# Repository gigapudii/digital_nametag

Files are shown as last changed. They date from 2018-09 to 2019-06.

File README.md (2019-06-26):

# Digital nametag
A digital nametag based on the Nokia 3310 screen, making you interesting during fairs.

## WHY
Whenever I visit fairs, I often feel that I am not noticed very much. And when I do find someone to speak to, I sometimes find it hard to start a conversation. 

digital-nametag-front

## HOW
The solution is a digital nametag. It can be used as a conversation starter and help show your creativity to the public. Aside of this, it gives you the possibility to present parts of your CV as well as contact information without having to spell it out loud everytime.

For the nametag you will need a screen to begin with. Nokia 3310 screens are big enough and apparently still sold online. Aside of this, you will need an Attiny85, a coin cell battery (CR2032), an on/off switch, and a button to power up the backlight of the screen. 

As for the microcontroller, the Attiny85 is preferred because it's a) low powered b) cheap and c) has just enough pins to drive the screen.

To design the board, Eagle CAD was used. The basic thought during the design process was to make it "invisible", i.e. have it hidden behind the screen, and for it to have a small cut on the top to be hanged through. Apart from this, the most important part was to make the correct connections between the board and the screen which was fairly straight forward. 

digital-nametag-back
digital-nametag-size

As for the software, the screen is controlled through an [Arduino library](https://github.com/platisd/nokia-5110-lcd-library). Additionally, when the screen is not updated, the microcontroller is in deep sleep to preserve the battery.

To create the images that were displayed on the screen, Adobe Photoshop and the LCD Assistant were mainly used.

## Components
* [Nametag PCB](https://oshpark.com/shared_projects/H9KOpiVm)
* Attiny85
* Coin cell battery CR2032
* Coin cell battery holder
* On/off switch
* Backlight button
* Resistor (for the backlight)

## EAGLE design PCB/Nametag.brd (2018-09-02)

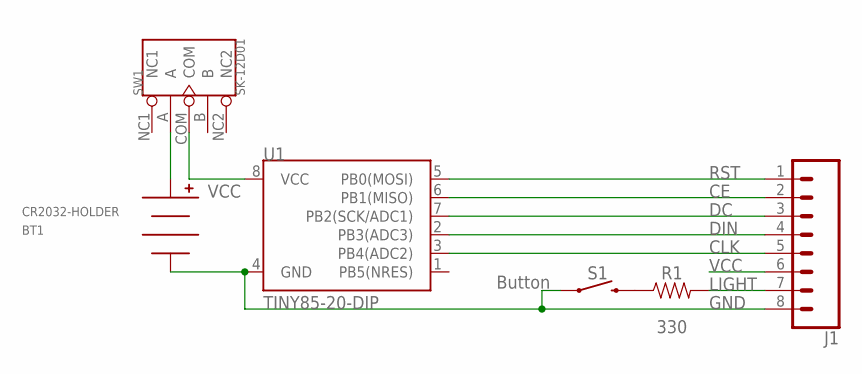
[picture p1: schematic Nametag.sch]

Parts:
BT1: CR2032-HOLDER; CH28-2032LF
J1: CONN_08"; 1X08
R1: 330; AXIAL-0.3
S1: Button; TACTILE_SWITCH_PTH_6.0MM
SW1: SK-12D01; SW5-2.0-8.8X4.4X4.7MM-90D
U1: TINY85-20-DIP; DIP08_MCU

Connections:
CE: J1.2, U1.6 (PB1(MISO))
CLK: J1.5, U1.3 (PB4(ADC2))
DC: J1.3, U1.7 (PB2(SCK/ADC1))
DIN: J1.4, U1.2 (PB3(ADC3))
GND: BT1.NEG, J1.8, S1.1, U1.4 (GND)
LIGHT: J1.7, R1.P$2 (2)
unnamed: R1.P$1 (1), S1.3 (2)
unnamed: BT1.POS, SW1.A
RST: J1.1, U1.5 (PB0(MOSI))
VCC: J1.6, SW1.COM, U1.8 (VCC)

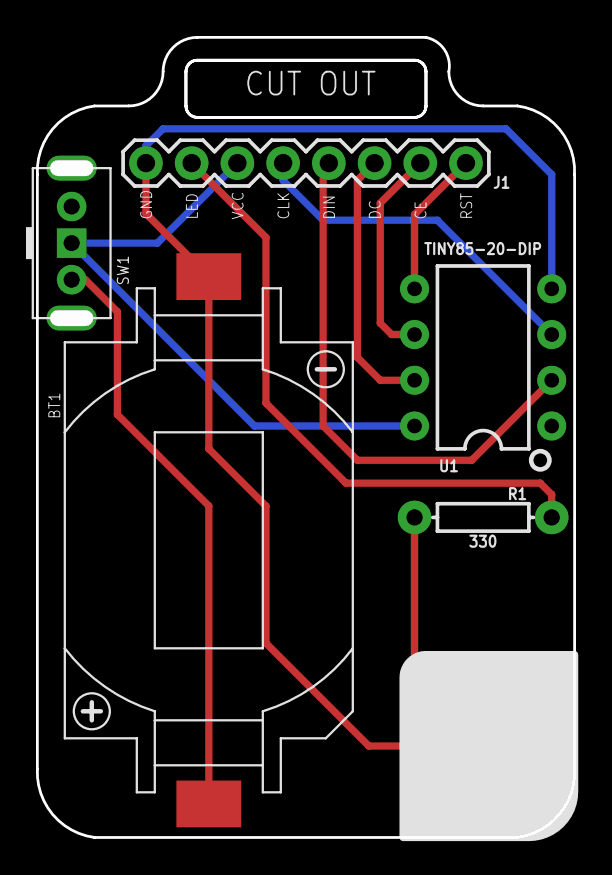
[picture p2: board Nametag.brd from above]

Board: 2 copper layers, 29.8 x 44.5 mm, 6 parts (0 on the bottom side), 10 nets.

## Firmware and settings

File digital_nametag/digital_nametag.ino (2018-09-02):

/**
 * Digital nametag
 * Author: Patricia Ilin aka Gigapudii
 * Bitmaps generated with LCD Assistant and Adobe Photoshop
 * Deep sleep code taken from https://github.com/platisd/dialectic-ball/
 * Nokia LCD library: https://github.com/platisd/nokia-5110-lcd-library
 */

#include <Nokia_LCD.h>
#include <avr/sleep.h>
#include <avr/power.h>
#include <avr/wdt.h>
#include <avr/interrupt.h>
#include <avr/pgmspace.h>

const unsigned char hellopic [] PROGMEM = {
0x00, 0xFC, 0xFC, 0x00, 0x00, 0xFC, 0xFC, 0x0C, 0x0C, 0xCC, 0xCC, 0xCC, 0xCC, 0xCC, 0xCC, 0xCC,
0xCC, 0xCC, 0xCC, 0xCC, 0xCC, 0xCC, 0xCC, 0xCC, 0xCC, 0xCC, 0xCC, 0xCC, 0xCC, 0xCC, 0xCC, 0xCC,
0xCC, 0xCC, 0xCC, 0xCC, 0xCC, 0xCC, 0xCC, 0xCC, 0xCC, 0xCC, 0xCC, 0xCC, 0xCC, 0xCC, 0xCC, 0xCC,
0xCC, 0xCC, 0xCC, 0xCC, 0xCC, 0xCC, 0xCC, 0xCC, 0xCC, 0xCC, 0xCC, 0xCC, 0xCC, 0xCC, 0xCC, 0xCC,
0xCC, 0xCC, 0xCC, 0xCC, 0xCC, 0xCC, 0xCC, 0xCC, 0xCC, 0xCC, 0xCC, 0xCC, 0xCC, 0xCC, 0x0C, 0x0C,
0xFC, 0xFC, 0x00, 0x00, 0x00, 0xFF, 0xFF, 0x00, 0x00, 0xFF, 0xFF, 0x00, 0x00, 0xFF, 0xFF, 0x00,
0x00, 0x00, 0xFC, 0xFC, 0x0C, 0x0C, 0x0C, 0x0C, 0x0C, 0x0C, 0x0C, 0x0C, 0x0C, 0x0C, 0x0C, 0x0C,
0x0C, 0x0C, 0x0C, 0x0C, 0x0C, 0x0C, 0x0C, 0x0C, 0x0C, 0x0C, 0x0C, 0x0C, 0x0C, 0x0C, 0x0C, 0x0C,
0x0C, 0x0C, 0x0C, 0x0C, 0x0C, 0x0C, 0x0C, 0x0C, 0x0C, 0x0C, 0x0C, 0x0C, 0x0C, 0x0C, 0x0C, 0x0C,
0x0C, 0x0C, 0x0C, 0x0C, 0x0C, 0x0C, 0x0C, 0x0C, 0x0C, 0x0C, 0x0C, 0x0C, 0xFC, 0xFC, 0x00, 0x00,
0xFF, 0xFF, 0x00, 0x00, 0xFF, 0xFF, 0x00, 0x00, 0x00, 0xFF, 0xFF, 0x00, 0x00, 0xFF, 0xFF, 0x00,
0x00, 0xFF, 0xFF, 0x00, 0x00, 0x00, 0xFF, 0xFF, 0x00, 0x00, 0x00, 0x00, 0x00, 0xFE, 0xFE, 0x20,
0x20, 0xFE, 0xFE, 0x00, 0x00, 0x00, 0x00, 0xFE, 0xFE, 0x22, 0x22, 0x22, 0x02, 0x00, 0x00, 0x00,
0x00, 0xFE, 0xFE, 0x00, 0x00, 0x00, 0x00, 0x00, 0x00, 0x00, 0x00, 0xFE, 0xFE, 0x00, 0x00, 0x00,
0x00, 0x00, 0x00, 0x00, 0x00, 0xFC, 0xFE, 0x02, 0x02, 0xFE, 0xFC, 0x00, 0x00, 0x00, 0x00, 0x00,
0xFF, 0xFF, 0x00, 0x00, 0xFF, 0xFF, 0x00, 0x00, 0xFF, 0xFF, 0x00, 0x00, 0x00, 0xFF, 0xFF, 0x00,
0x00, 0xFF, 0xFF, 0x00, 0x00, 0xFF, 0xFF, 0x00, 0x00, 0x00, 0xFF, 0xFF, 0x00, 0x00, 0x00, 0x00,
0x00, 0x03, 0x03, 0x00, 0x00, 0x03, 0x03, 0x00, 0x00, 0x00, 0x00, 0x03, 0x03, 0x02, 0x02, 0x02,
0x02, 0x00, 0x00, 0x00, 0x00, 0x03, 0x03, 0x02, 0x02, 0x02, 0x02, 0x00, 0x00, 0x00, 0x00, 0x03,
0x03, 0x02, 0x02, 0x02, 0x02, 0x00, 0x00, 0x00, 0x00, 0x01, 0x03, 0x02, 0x02, 0x03, 0x01, 0x00,
0x00, 0x00, 0x00, 0x00, 0xFF, 0xFF, 0x00, 0x00, 0xFF, 0xFF, 0x00, 0x00, 0xFF, 0xFF, 0x00, 0x00,
0x00, 0xFF, 0xFF, 0x00, 0x00, 0xFF, 0xFF, 0x00, 0x00, 0x3F, 0x3F, 0x30, 0x30, 0x30, 0x33, 0x33,
0x33, 0x33, 0x33, 0x33, 0x33, 0x33, 0x33, 0x33, 0x33, 0x33, 0x33, 0x33, 0x33, 0x33, 0x33, 0x33,
0x33, 0x33, 0x33, 0x33, 0x33, 0x33, 0x33, 0x33, 0x33, 0x33, 0x33, 0x33, 0x33, 0x33, 0x33, 0x33,
0x33, 0x33, 0x33, 0x33, 0x33, 0x33, 0x33, 0x33, 0x33, 0x33, 0x33, 0x33, 0x33, 0x33, 0x33, 0x33,
0x33, 0x33, 0x33, 0x33, 0x33, 0x33, 0x30, 0x30, 0x3F, 0x3F, 0x00, 0x00, 0xFF, 0xFF, 0x00, 0x00,
0xFF, 0xFF, 0x00, 0x00, 0x00, 0x3F, 0x3F, 0x30, 0x30, 0x33, 0x33, 0x33, 0x33, 0x33, 0x33, 0x33,
0x33, 0x33, 0x33, 0x33, 0x33, 0x33, 0x33, 0x33, 0x33, 0x33, 0x33, 0x33, 0x33, 0x33, 0x33, 0x33,
0x33, 0x33, 0x33, 0x33, 0x33, 0x33, 0x33, 0x33, 0x33, 0x33, 0x33, 0x33, 0x33, 0x33, 0x33, 0x33,
0x33, 0x33, 0x33, 0x33, 0x33, 0x33, 0x33, 0x33, 0x33, 0x33, 0x33, 0x33, 0x33, 0x33, 0x33, 0x33,
0x33, 0x33, 0x33, 0x33, 0x33, 0x33, 0x33, 0x33, 0x33, 0x33, 0x33, 0x33, 0x33, 0x33, 0x33, 0x33,
0x33, 0x33, 0x30, 0x30, 0x3F, 0x3F, 0x00, 0x00, 
};

const unsigned char nicetomeetyou [] PROGMEM = {
0x00, 0x00, 0xFC, 0x18, 0x60, 0x80, 0xFC, 0x00, 0x00, 0xF4, 0x00, 0x00, 0xE0, 0x10, 0x10, 0x10,
0x00, 0xE0, 0x50, 0x50, 0x60, 0x00, 0x00, 0x00, 0x00, 0x10, 0xF8, 0x10, 0x00, 0xE0, 0x10, 0x10,
0x10, 0xE0, 0x00, 0x00, 0x00, 0x00, 0xF0, 0x10, 0x10, 0xF0, 0x10, 0xF0, 0x00, 0x00, 0xE0, 0x50,
0x50, 0x60, 0x00, 0xE0, 0x50, 0x50, 0x60, 0x00, 0x10, 0xF8, 0x10, 0x00, 0x00, 0x00, 0x00, 0x70,
0x80, 0xC0, 0x30, 0x00, 0xE0, 0x10, 0x10, 0x10, 0xE0, 0x00, 0xF0, 0x00, 0x00, 0xF0, 0x00, 0x00,
0x00, 0x7C, 0x00, 0x00, 0x00, 0x00, 0x83, 0x00, 0x00, 0x01, 0x83, 0x00, 0x00, 0x03, 0x00, 0x00,
0x01, 0x02, 0x02, 0x02, 0x00, 0x01, 0x02, 0x82, 0x82, 0x80, 0x80, 0x00, 0x00, 0x00, 0x03, 0x02,
0x00, 0x01, 0x02, 0x02, 0x02, 0x01, 0x00, 0x00, 0x00, 0x00, 0x03, 0x80, 0x00, 0x03, 0x00, 0x03,
0x00, 0x00, 0x81, 0x02, 0x02, 0x02, 0x00, 0x01, 0x02, 0x02, 0x02, 0x00, 0x00, 0x03, 0x02, 0x00,
0x00, 0x00, 0x00, 0x10, 0x1F, 0x03, 0x00, 0x00, 0x01, 0x02, 0x02, 0x02, 0x01, 0x00, 0x03, 0x02,
0x02, 0x03, 0x00, 0x00, 0x00, 0x03, 0x00, 0x00, 0x00, 0x00, 0x7F, 0x00, 0x00, 0x00, 0x01, 0x00,
0x7E, 0x02, 0x02, 0x7E, 0x02, 0x7E, 0x00, 0x00, 0x00, 0x00, 0x00, 0x7F, 0x08, 0x08, 0x0C, 0x07,
0x00, 0x70, 0x52, 0x12, 0x7E, 0x00, 0x00, 0x02, 0x7F, 0x42, 0x00, 0x7E, 0x02, 0x02, 0x00, 0x7E,
0x00, 0x3C, 0x42, 0x42, 0x42, 0x00, 0x7E, 0x00, 0x00, 0x70, 0x52, 0x12, 0x7E, 0x00, 0x00, 0x60,
0x00, 0x00, 0x00, 0x00, 0x00, 0x00, 0x00, 0x00, 0x00, 0x00, 0x00, 0x00, 0x00, 0x00, 0x00, 0x00,
0x00, 0x00, 0x00, 0x00, 0x00, 0x00, 0x00, 0x00, 0x00, 0x00, 0x00, 0x00, 0x00, 0x00, 0x00, 0x00,
0x00, 0x00, 0x00, 0x00, 0x00, 0x00, 0x00, 0x00, 0x00, 0x00, 0x00, 0x00, 0x00, 0x00, 0x00, 0x00,
0x00, 0x00, 0x00, 0x00, 0x00, 0x00, 0x00, 0x00, 0x00, 0x00, 0x00, 0x00, 0x00, 0x00, 0x00, 0x00,
0x00, 0x00, 0x00, 0x00, 0x00, 0x00, 0x00, 0x00, 0x00, 0x00, 0x00, 0x00, 0x00, 0x00, 0x00, 0x00,
0x00, 0x00, 0x00, 0x00, 0x00, 0x00, 0x00, 0x00, 0x00, 0x00, 0x00, 0x00, 0x00, 0x00, 0x00, 0x00,
0x00, 0x00, 0x00, 0x00, 0x00, 0x00, 0x00, 0x00, 0x00, 0x00, 0x00, 0x00, 0x00, 0x00, 0x00, 0x00,
0x00, 0x00, 0xF8, 0x80, 0x80, 0xF8, 0x00, 0xE0, 0x30, 0x18, 0x18, 0x38, 0xE0, 0x00, 0x78, 0xE0,
0x80, 0x78, 0x80, 0xE0, 0x38, 0x00, 0x00, 0x00, 0x00, 0x00, 0xF0, 0x18, 0xE0, 0x00, 0x00, 0x00,
0xF8, 0x98, 0xF0, 0x00, 0x00, 0xE0, 0x30, 0x18, 0x18, 0x38, 0xE0, 0x00, 0x00, 0x00, 0xF8, 0x00,
0x00, 0xF8, 0x00, 0x00, 0x18, 0xF8, 0x18, 0x00, 0x00, 0x00, 0x00, 0x08, 0x78, 0x80, 0xF8, 0x08,
0x00, 0xE0, 0x30, 0x18, 0x18, 0x38, 0xE0, 0x00, 0x00, 0xF8, 0x00, 0x00, 0xF8, 0x00, 0x10, 0x18,
0xF0, 0x00, 0x00, 0x00, 0x00, 0x00, 0x3F, 0x01, 0x01, 0x3F, 0x00, 0x0F, 0x38, 0x30, 0x30, 0x18,
0x0F, 0x00, 0x00, 0x3F, 0x3F, 0x00, 0x3F, 0x3F, 0x00, 0x00, 0x00, 0x00, 0x00, 0x38, 0x0F, 0x06,
0x1F, 0x38, 0x00, 0x00, 0x3F, 0x31, 0x31, 0x1F, 0x00, 0x0F, 0x38, 0x30, 0x30, 0x18, 0x0F, 0x00,
0x00, 0x00, 0x1F, 0x30, 0x30, 0x1F, 0x00, 0x00, 0x00, 0x3F, 0x00, 0x00, 0x00, 0x00, 0x00, 0x00,
0x00, 0x3F, 0x00, 0x00, 0x00, 0x0F, 0x38, 0x30, 0x30, 0x18, 0x0F, 0x00, 0x00, 0x1F, 0x30, 0x30,
0x1F, 0x00, 0x00, 0x3B, 0x00, 0x00, 0x00, 0x00, 
};

const unsigned char datatjej_logo [] PROGMEM = {
  0x00, 0x00, 0x00, 0x00, 0x00, 0x00, 0x00, 0x00, 0x00, 0x00, 0x00, 0x00, 0x00, 0x00, 0x00, 0x00,
  0x00, 0x00, 0x00, 0x00, 0x00, 0x00, 0x00, 0x00, 0x00, 0x00, 0xFF, 0xFF, 0xFF, 0xFF, 0xFF, 0xFF,
  0xFF, 0xFF, 0xFF, 0xFF, 0xFF, 0xFF, 0xFF, 0xFF, 0xFF, 0xFF, 0xFF, 0xFF, 0xFF, 0xFF, 0xFF, 0xFF,
  0xFF, 0xFF, 0xFF, 0xFF, 0xFF, 0xFF, 0xFF, 0xFF, 0xFF, 0xFF, 0x00, 0x00, 0x00, 0x00, 0x00, 0x00,
  0x00, 0x00, 0x00, 0x00, 0x00, 0x00, 0x00, 0x00, 0x00, 0x00, 0x00, 0x00, 0x00, 0x00, 0x00, 0x00,
  0x00, 0x00, 0x00, 0x00, 0x00, 0x00, 0x00, 0x00, 0x00, 0x00, 0x00, 0x00, 0x00, 0x00, 0x00, 0x00,
  0x00, 0x00, 0x00, 0x00, 0x00, 0x00, 0x00, 0x00, 0x00, 0x00, 0x00, 0x00, 0x00, 0x00, 0xFF, 0xFF,
  0xFF, 0xFF, 0xFF, 0xFF, 0xFF, 0xFF, 0x00, 0x00, 0x00, 0x00, 0x00, 0x00, 0x00, 0x00, 0x00, 0x00,
  0x00, 0x00, 0x00, 0x00, 0x00, 0x00, 0xFF, 0xFF, 0xFF, 0xFF, 0xFF, 0xFF, 0xFF, 0xFF, 0x00, 0x00,
  0x00, 0x00, 0x00, 0x00, 0x00, 0x00, 0x00, 0x00, 0x00, 0x00, 0x00, 0x00, 0x00, 0x00, 0x00, 0x00,
  0x00, 0x00, 0x00, 0x00, 0x00, 0x00, 0x00, 0x00, 0x00, 0x00, 0x00, 0x00, 0x00, 0x00, 0x00, 0x00,
  0x00, 0x00, 0x00, 0x00, 0x00, 0x00, 0x00, 0x00, 0x00, 0x00, 0x00, 0x00, 0x00, 0x00, 0x00, 0x00,
  0x00, 0x00, 0xFF, 0xFF, 0xFF, 0xFF, 0xFF, 0xFF, 0xFF, 0xFF, 0x00, 0x00, 0x00, 0x00, 0x00, 0x00,
  0x00, 0x00, 0x00, 0x00, 0x00, 0x00, 0x00, 0x00, 0x00, 0x00, 0xFF, 0xFF, 0xFF, 0xFF, 0xFF, 0xFF,
  0xFF, 0xFF, 0x00, 0x00, 0x00, 0x00, 0x00, 0x00, 0x00, 0x00, 0x00, 0x00, 0x00, 0x00, 0x00, 0x00,
  0x00, 0x00, 0x00, 0x00, 0x00, 0x00, 0x00, 0x00, 0x00, 0x00, 0x00, 0x00, 0x00, 0x00, 0x00, 0x00,
  0x00, 0x00, 0x00, 0x00, 0x00, 0x00, 0x00, 0x00, 0x00, 0x00, 0x00, 0x00, 0x00, 0x00, 0xFF, 0xFF,
  0xFF, 0xFF, 0xFF, 0xFF, 0xFF, 0xFF, 0x00, 0x00, 0x00, 0x00, 0x00, 0x00, 0x00, 0x00, 0xFF, 0xFF,
  0xFF, 0xFF, 0xFF, 0xFF, 0xFF, 0xFF, 0xFF, 0xFF, 0xFF, 0xFF, 0xFF, 0xFF, 0xFF, 0xFF, 0x00, 0x00,
  0x00, 0x00, 0x00, 0x00, 0x00, 0x00, 0xFF, 0xFF, 0xFF, 0xFF, 0xFF, 0xFF, 0xFF, 0xFF, 0x00, 0x00,
  0x00, 0x00, 0x00, 0x00, 0x00, 0x00, 0x00, 0x00, 0x00, 0x00, 0x00, 0x00, 0x00, 0x00, 0x00, 0x00,
  0x00, 0x00, 0x00, 0x00, 0x00, 0x00, 0x00, 0x00, 0x00, 0x00, 0x00, 0x00, 0x00, 0x00, 0x00, 0x00,
  0x00, 0x00, 0x00, 0x00, 0x00, 0x00, 0x00, 0x00, 0x00, 0x00, 0xFF, 0xFF, 0xFF, 0xFF, 0xFF, 0xFF,
  0xFF, 0xFF, 0xFF, 0xFF, 0xFF, 0xFF, 0xFF, 0xFF, 0xFF, 0xFF, 0xFF, 0xFF, 0xFF, 0xFF, 0xFF, 0xFF,
  0xFF, 0xFF, 0xFF, 0xFF, 0xFF, 0xFF, 0xFF, 0xFF, 0xFF, 0xFF, 0x00, 0x00, 0x00, 0x00, 0x00, 0x00,
  0x00, 0x00, 0x00, 0x00, 0x00, 0x00, 0x00, 0x00, 0x00, 0x00, 0x00, 0x00, 0x00, 0x00, 0x00, 0x00,
  0x00, 0x00, 0x00, 0x00, 0x00, 0x00, 0x00, 0x00, 0x00, 0x00, 0x00, 0x00, 0x00, 0x00, 0x00, 0x00,
  0x00, 0x00, 0x00, 0x00, 0x00, 0x00, 0x00, 0x00, 0x00, 0x00, 0x00, 0x00, 0x00, 0x00, 0x00, 0x00,
  0x00, 0x00, 0x00, 0x00, 0x00, 0x00, 0xFF, 0xFF, 0xFF, 0xFF, 0xFF, 0xFF, 0xFF, 0xFF, 0xFF, 0xFF,
  0xFF, 0xFF, 0xFF, 0xFF, 0xFF, 0xFF, 0x00, 0x00, 0x00, 0x00, 0x00, 0x00, 0x00, 0x00, 0x00, 0x00,
  0x00, 0x00, 0x00, 0x00, 0x00, 0x00, 0x00, 0x00, 0x00, 0x00, 0x00, 0x00, 0x00, 0x00, 0x00, 0x00,
  0x00, 0x00, 0x00, 0x00, 0x00, 0x00, 0x00, 0x00,
};

const unsigned char contact3 [] PROGMEM = {
0x00, 0xF8, 0xFC, 0xFE, 0xFE, 0x8E, 0x8E, 0x8E, 0xFE, 0xFE, 0xFE, 0xFE, 0xFE, 0xFE, 0xFE, 0xFE,
0xFE, 0xFE, 0xFE, 0xFC, 0xFC, 0xF8, 0x00, 0x00, 0x00, 0x80, 0x00, 0x00, 0x80, 0x00, 0x00, 0x80,
0x00, 0x00, 0x00, 0x00, 0x00, 0x00, 0x00, 0x00, 0x00, 0x00, 0x00, 0x00, 0x00, 0x00, 0x00, 0x00,
0x00, 0x00, 0x00, 0x00, 0x00, 0x00, 0x00, 0x00, 0x00, 0x00, 0x00, 0x00, 0x00, 0x00, 0x00, 0x00,
0x00, 0x80, 0x00, 0x00, 0x00, 0x00, 0x00, 0x00, 0x00, 0x00, 0x80, 0x00, 0x00, 0x00, 0x00, 0x00,
0x00, 0x00, 0x00, 0x00, 0x00, 0xFF, 0xFF, 0xFF, 0xFF, 0x00, 0x00, 0x00, 0xFF, 0xFF, 0x00, 0x00,
0x00, 0xFC, 0xFC, 0xFC, 0x00, 0x00, 0x00, 0xFF, 0xFF, 0xFF, 0x00, 0x00, 0x00, 0x7E, 0x00, 0x00,
0x7F, 0x00, 0x00, 0x7E, 0x00, 0x00, 0x00, 0x7E, 0x06, 0x02, 0x02, 0x7E, 0x00, 0x00, 0xFC, 0x26,
0x42, 0x42, 0x66, 0x3C, 0x00, 0x70, 0x52, 0x12, 0x7E, 0x00, 0x00, 0x00, 0x02, 0x7F, 0x42, 0x00,
0x7E, 0x04, 0x02, 0x02, 0x00, 0x7E, 0x00, 0x00, 0x00, 0x3C, 0x42, 0x42, 0x42, 0x00, 0x7E, 0x00,
0x00, 0x70, 0x52, 0x12, 0x7E, 0x00, 0x00, 0x00, 0x00, 0x07, 0x0F, 0x1F, 0x1F, 0x1E, 0x1E, 0x1E,
0x1F, 0x1F, 0x1E, 0x1E, 0x1E, 0x1F, 0x1F, 0x1F, 0x1E, 0x1E, 0x1E, 0x1F, 0x0F, 0x07, 0x00, 0x00,
0x00, 0x00, 0x00, 0x00, 0x00, 0x00, 0x00, 0x00, 0x00, 0x00, 0x00, 0x00, 0x00, 0x00, 0x00, 0x00,
0x00, 0x00, 0x03, 0x00, 0x00, 0x00, 0x00, 0x00, 0x00, 0x00, 0x00, 0x00, 0x00, 0x00, 0x00, 0x00,
0x00, 0x00, 0x00, 0x00, 0x00, 0x00, 0x00, 0x00, 0x00, 0x00, 0x00, 0x00, 0x00, 0x00, 0x00, 0x00,
0x00, 0x00, 0x00, 0x00, 0x00, 0x00, 0x00, 0x00, 0x00, 0x00, 0x00, 0x00, 0x00, 0xF0, 0xF8, 0xFC,
0xFC, 0x7C, 0x3C, 0x3C, 0x3C, 0x3C, 0x7C, 0xFC, 0xFC, 0xFC, 0xFC, 0xFC, 0xFC, 0xFC, 0xFC, 0xF8,
0xF8, 0xF0, 0x00, 0x00, 0x00, 0x80, 0x80, 0x00, 0x00, 0x00, 0x80, 0x80, 0x80, 0x80, 0x00, 0x80,
0x80, 0x80, 0x80, 0x00, 0x00, 0x00, 0x80, 0x80, 0x80, 0x80, 0x00, 0x00, 0x00, 0x00, 0x80, 0x00,
0x00, 0x00, 0x80, 0x80, 0x80, 0x80, 0x00, 0x00, 0x80, 0x80, 0x00, 0x00, 0x00, 0x00, 0x80, 0x80,
0x80, 0x80, 0x00, 0x00, 0x80, 0x80, 0x00, 0x00, 0x00, 0x00, 0x80, 0x80, 0x80, 0x00, 0x00, 0x00,
0x00, 0xFF, 0xFF, 0xFF, 0xFF, 0xFC, 0xF0, 0xE0, 0xC0, 0x88, 0x1C, 0x3F, 0x3F, 0x0F, 0x0F, 0x0F,
0x1F, 0xFF, 0xFF, 0xFF, 0xFF, 0xFF, 0x00, 0x00, 0x3F, 0x40, 0x40, 0x3F, 0x00, 0x00, 0x40, 0x30,
0x0E, 0x01, 0x00, 0x40, 0x44, 0x44, 0x3B, 0x00, 0x00, 0x00, 0x40, 0x30, 0x0E, 0x01, 0x00, 0x38,
0x46, 0x45, 0x44, 0x38, 0x00, 0x00, 0x40, 0x30, 0x0E, 0x01, 0x00, 0x00, 0x01, 0x7F, 0x00, 0x00,
0x00, 0x00, 0x47, 0x44, 0x44, 0x38, 0x00, 0x00, 0x01, 0x7F, 0x00, 0x00, 0x00, 0x3B, 0x44, 0x44,
0x44, 0x3B, 0x00, 0x00, 0x00, 0x0F, 0x1F, 0x3F, 0x3F, 0x3F, 0x3F, 0x3F, 0x3F, 0x3F, 0x3F, 0x3E,
0x3E, 0x3E, 0x3E, 0x3E, 0x3F, 0x3F, 0x3F, 0x3F, 0x1F, 0x0F, 0x00, 0x00, 0x00, 0x00, 0x00, 0x00,
0x00, 0x00, 0x00, 0x00, 0x00, 0x00, 0x00, 0x00, 0x00, 0x00, 0x00, 0x00, 0x00, 0x00, 0x00, 0x00,
0x00, 0x00, 0x00, 0x00, 0x00, 0x00, 0x00, 0x00, 0x00, 0x00, 0x00, 0x00, 0x00, 0x00, 0x00, 0x00,
0x00, 0x00, 0x00, 0x00, 0x00, 0x00, 0x00, 0x00, 0x00, 0x00, 0x00, 0x00, 0x00, 0x00, 0x00, 0x00,
0x00, 0x00, 0x00, 0x00, 0x00, 0x00, 0x00, 0x00, 
};

const unsigned char seeyouonline [] PROGMEM = {
0x00, 0x00, 0x00, 0x00, 0x00, 0x00, 0xE0, 0x30, 0x30, 0x00, 0x00, 0x80, 0x80, 0x00, 0x00, 0x00,
0x00, 0x80, 0x80, 0x00, 0x00, 0x00, 0x00, 0x00, 0x80, 0x80, 0x00, 0x80, 0x80, 0x00, 0x00, 0x00,
0x80, 0x80, 0x00, 0x00, 0x00, 0x80, 0x00, 0x00, 0x80, 0x00, 0x00, 0x00, 0x00, 0x00, 0x00, 0x80,
0x80, 0x00, 0x00, 0x00, 0x00, 0x80, 0x80, 0x80, 0x00, 0x00, 0x00, 0xF8, 0x00, 0x00, 0x00, 0xB0,
0x00, 0x00, 0x80, 0x80, 0x80, 0x00, 0x00, 0x00, 0x00, 0x80, 0x80, 0x00, 0x00, 0x00, 0xF0, 0x00,
0x00, 0x00, 0x00, 0x00, 0x00, 0x00, 0x00, 0x00, 0x00, 0x00, 0x71, 0x67, 0x3E, 0x00, 0x3F, 0x6D,
0x6D, 0x6F, 0x00, 0x00, 0x3F, 0x6D, 0x6D, 0x6F, 0x00, 0x00, 0x00, 0x00, 0x01, 0x1F, 0xF0, 0x3F,
0x01, 0x00, 0x00, 0x3F, 0x61, 0x61, 0x3F, 0x00, 0x00, 0x3F, 0x60, 0x60, 0x7F, 0x00, 0x00, 0x00,
0x00, 0x00, 0x3F, 0x61, 0x61, 0x3F, 0x00, 0x00, 0x00, 0x7F, 0x01, 0x01, 0x7F, 0x00, 0x00, 0x7F,
0x00, 0x00, 0x00, 0x7F, 0x00, 0x00, 0x7F, 0x01, 0x01, 0x7F, 0x00, 0x00, 0x3F, 0x6D, 0x6D, 0x6F,
0x00, 0x00, 0x77, 0x00, 0x00, 0x00, 0x00, 0x00, 0x00, 0x00, 0x00, 0x00, 0x00, 0x00, 0x00, 0x00,
0x00, 0x00, 0x00, 0x00, 0x00, 0x00, 0x00, 0x00, 0x00, 0x00, 0x00, 0x00, 0x00, 0x00, 0x00, 0x00,
0x04, 0x03, 0x01, 0x00, 0x00, 0x00, 0x80, 0xC0, 0xC0, 0x00, 0x00, 0x00, 0x00, 0x00, 0x00, 0x00,
0x00, 0x00, 0x00, 0x00, 0x00, 0x00, 0x00, 0x00, 0x00, 0xC0, 0xC0, 0x80, 0x00, 0x00, 0x00, 0x00,
0x00, 0x00, 0x00, 0x00, 0x00, 0x00, 0x00, 0x00, 0x00, 0x00, 0x00, 0x00, 0x00, 0x00, 0x00, 0x00,
0x00, 0x00, 0x00, 0x00, 0x00, 0x00, 0x00, 0x00, 0x00, 0x00, 0x00, 0x00, 0x00, 0x00, 0x00, 0x00,
0x00, 0x00, 0x00, 0x00, 0x00, 0x00, 0x00, 0x00, 0x00, 0x00, 0x00, 0x00, 0x00, 0x00, 0x00, 0x00,
0x00, 0x00, 0x00, 0x00, 0x00, 0x00, 0xC0, 0xF8, 0x3E, 0x1F, 0x03, 0xC1, 0xE0, 0x78, 0x1C, 0x1E,
0x06, 0x00, 0x80, 0xC0, 0xE0, 0xE0, 0xC0, 0x80, 0x00, 0x06, 0x1E, 0x1C, 0x78, 0xE0, 0xC1, 0x03,
0x1F, 0x3E, 0xF8, 0xC0, 0x00, 0x00, 0x00, 0x00, 0x00, 0x00, 0x00, 0x00, 0x00, 0x00, 0x00, 0x00,
0x00, 0x00, 0x00, 0x00, 0x00, 0x00, 0x00, 0x00, 0x00, 0x00, 0x00, 0x00, 0x00, 0x00, 0x00, 0x00,
0x00, 0x00, 0x00, 0x00, 0x00, 0x00, 0x00, 0x00, 0x00, 0x00, 0x00, 0x00, 0x00, 0x00, 0x00, 0x00,
0x00, 0x00, 0x00, 0x00, 0x00, 0x00, 0x00, 0x00, 0x00, 0x00, 0x0F, 0xFF, 0xE0, 0xC0, 0x00, 0x1F,
0x3F, 0x70, 0xC0, 0xC0, 0x80, 0x03, 0x07, 0x0F, 0xFF, 0xFF, 0x0F, 0x07, 0x03, 0x80, 0xC0, 0xC0,
0x70, 0x3F, 0x1F, 0x00, 0xC0, 0xE0, 0xFF, 0x0F, 0x00, 0x00, 0x00, 0x00, 0x00, 0x00, 0x00, 0x00,
0x00, 0x00, 0x00, 0x00, 0x00, 0x00, 0x00, 0x00, 0x00, 0x00, 0x00, 0x00, 0x00, 0x00, 0x00, 0x00,
0x00, 0x00, 0x00, 0x00, 0x00, 0x00, 0x00, 0x00, 0x00, 0x00, 0x00, 0x00, 0x00, 0x00, 0x00, 0x00,
0x00, 0x00, 0x00, 0x00, 0x00, 0x00, 0x00, 0x00, 0x00, 0x00, 0x00, 0x00, 0x00, 0x00, 0x00, 0x00,
0x03, 0x03, 0x0E, 0x1C, 0x1C, 0x00, 0x01, 0x01, 0x01, 0x00, 0x00, 0x00, 0xFF, 0xFF, 0x00, 0x00,
0x00, 0x01, 0x01, 0x01, 0x00, 0x1C, 0x1C, 0x0E, 0x03, 0x03, 0x00, 0x00, 0x00, 0x00, 0x00, 0x00,
0x00, 0x00, 0x00, 0x00, 0x00, 0x00, 0x00, 0x00, 0x00, 0x00, 0x00, 0x00, 0x00, 0x00, 0x00, 0x00,
0x00, 0x00, 0x00, 0x00, 0x00, 0x00, 0x00, 0x00, 
};

Nokia_LCD lcd(PB4 /* CLK */, PB3 /* DIN */, PB2 /* DC */, PB1 /* CE */, PB0 /* RST */);

volatile bool watchdogBarked = false;

enum WatchDogTimeout {
  WDT_16ms = 0,
  WDT_32ms,
  WDT_64ms,
  WDT_128ms,
  WDT_250ms,
  WDT_500ms,
  WDT_1sec,
  WDT_2sec,
  WDT_4sec,
  WDT_8sec
};

/**
  Watchdog interrupt routine to be triggered when watchdog times out.
*/
ISR(WDT_vect) {
  watchdogBarked = true;
}

void goToSleep() {
  set_sleep_mode(SLEEP_MODE_PWR_DOWN);
  power_all_disable ();
  sleep_enable();
  sleep_cpu(); // Sleep here and wait for the interrupt
  sleep_disable();
  power_all_enable(); // power everything back on
}

/**
    Sets up watchdog to be triggered (once) after the specified time
    @param wdt  the watchdog timeout duration
*/
void triggerWatchDogIn(WatchDogTimeout wdt) {
  // Adopted from InsideGadgets (www.insidegadgets.com)
  byte timeoutVal = wdt & 7;
  if (wdt > 7) {
    timeoutVal |= (1 << 5);
  }
  timeoutVal |= (1 << WDCE);

  MCUSR &= ~(1 << WDRF);
  WDTCR |= (1 << WDCE) | (1 << WDE); // Start timed sequence
  WDTCR = timeoutVal;
  WDTCR |= _BV(WDIE);
  wdt_reset(); // Pat the dog
}

/**
   A utility method to derive a watchdog timeout's duration
   @param wdt the watchdog timeout
   @return    the amount of milliseconds corresponding to a watchdog timeout
*/
unsigned long getTimeoutDuration(WatchDogTimeout wdt) {
  return 1 << (wdt + 4);
}


/**
   Blocks and stays in deep sleep until the specified time has elapsed
   using the current watchdog timeout.
   @param sleepDuration     how long to stay in deep sleep in milliseconds
   @param timeoutInterval   the watchdog timeout interval
*/
void stayInDeepSleepFor(unsigned long sleepDuration, WatchDogTimeout timeoutInterval = WDT_16ms) {
  unsigned long sleepTime = 0;

  // Start by triggering the watchdog to wake us up every `timeoutInterval`
  triggerWatchDogIn(timeoutInterval);
  while (sleepTime <= sleepDuration) {
    // Sleep until an interrupt occurs (external, change or watchdog)
    goToSleep();
    // Verify we woke up because of the watchdog and not
    // a spurious wake up due to some other unrelated interrupt.
    if (watchdogBarked) {
      // Note down that we have processed the watchdog bark
      watchdogBarked = false;
      // Increase the time we have already slept
      sleepTime += getTimeoutDuration(timeoutInterval);
    }
  }
  wdt_disable(); // Disable watchdog so it stops barking
}

void setup() {
  // Initialize the screen
  lcd.begin();
  lcd.setCursor(0, 0);
}

void loop() {
  // put your main code here, to run repeatedly:
  // Draw the lcd pic on your screen
  lcd.draw(hellopic, 504);
  stayInDeepSleepFor(3000);
  // Draw the contact on your screen
  lcd.draw(nicetomeetyou, 504);
  stayInDeepSleepFor(10000);
  // Draw the datatjej logo on your screen
  lcd.draw(datatjej_logo, 504);
  stayInDeepSleepFor(4500);
  // Draw the contact info on your screen
  lcd.draw(contact3, 504);
  stayInDeepSleepFor(15000);
  // Draw the seeyouonline pic on your screen
  lcd.draw(seeyouonline, 504);
  stayInDeepSleepFor(3000);
}

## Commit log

2018-09-02 add arduino sketch
2018-09-02 add PCB
    [Nametag.brd, Nametag.sch]

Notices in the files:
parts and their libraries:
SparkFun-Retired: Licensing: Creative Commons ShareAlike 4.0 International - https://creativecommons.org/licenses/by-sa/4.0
